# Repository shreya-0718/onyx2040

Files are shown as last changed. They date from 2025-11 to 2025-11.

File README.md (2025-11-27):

# Onyx2040
This is a devboard powered by the RP2040 chip! It features 40 pins broken out (20 per side) for easy prototyping and a plus‑sign of 5 RGB LEDs to animate whatever your heart desires.

I built this project as a way to learn full PCB design, from schematics to routing to firmware. It’s also a great way for others to prototype their own ideas, with colorful lighting built in to make experimentation more fun and expressive.

## How to Use It?
1. **Power the board** with USB-C
2. To use MicroPython, hold the button (the board will appear as a USB drive named RPI-RP2) and **flash the MicroPython UF2 firmware** with the [MicroPython RP2040 Documentation](https://www.raspberrypi.com/documentation/microcontrollers/micropython.html).
3. Once MicroPython is installed, **copy your Python files** to the board.
4. Then, **experiment!** Use the 40 broken‑out pins (GPIO, power, and ground) to connect sensors, modules, or breadboards. Check out the firmware in the /firmware folder in this repository for an example of how to control the on-board LEDs. Enjoy!

## Images
Here is the **schematic**:

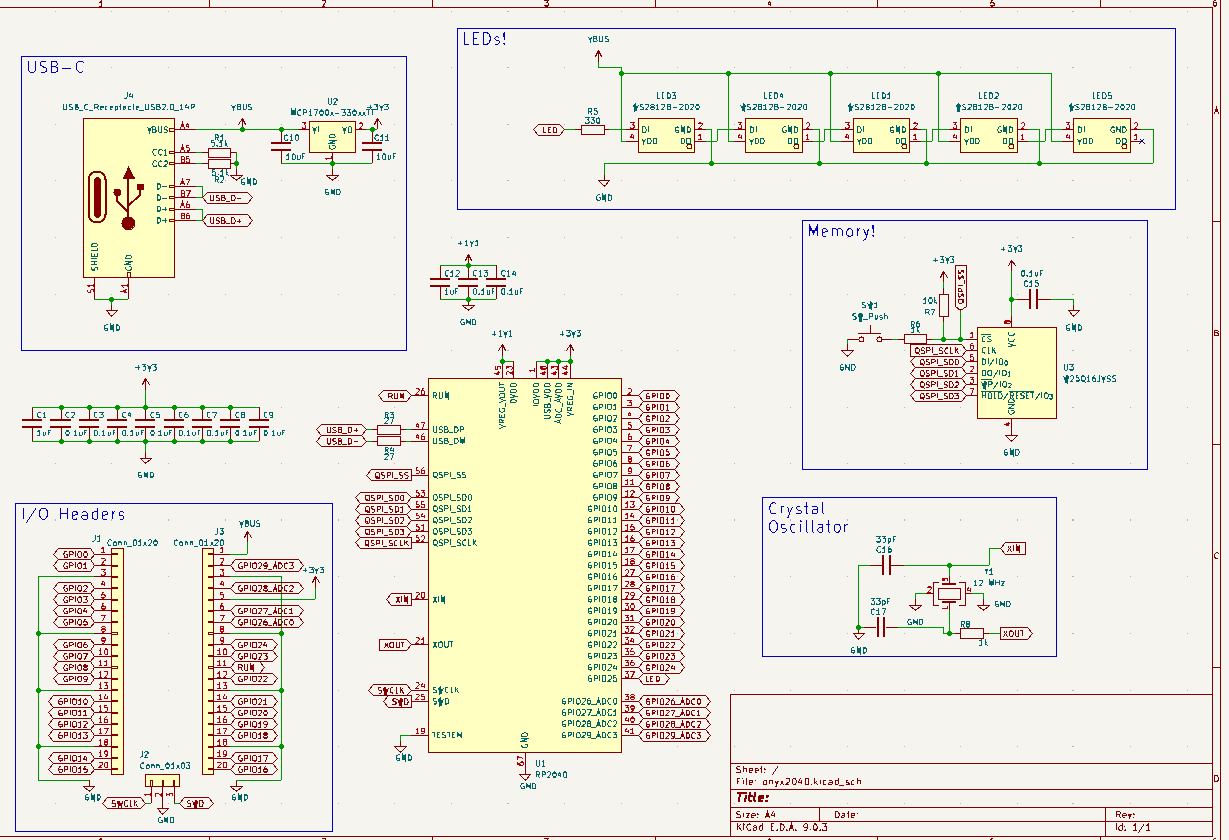
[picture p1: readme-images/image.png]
schematic


And here is the **finished PCB** in the editor:

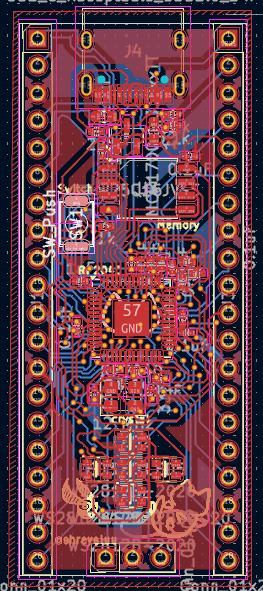
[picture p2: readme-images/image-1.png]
pcb in editor


This is what the **final devboard** will look like:

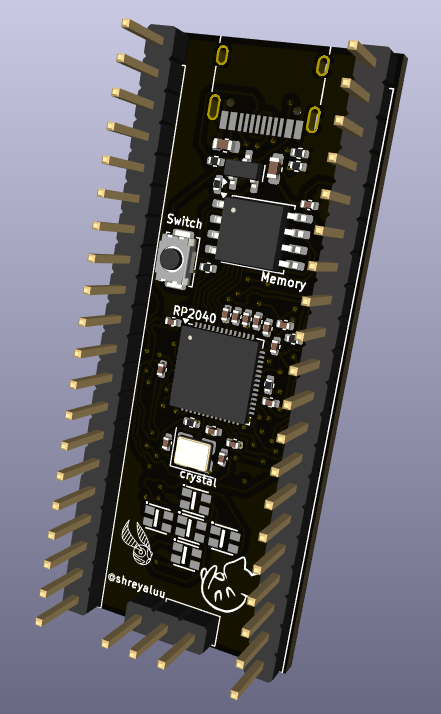
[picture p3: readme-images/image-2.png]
devboard front

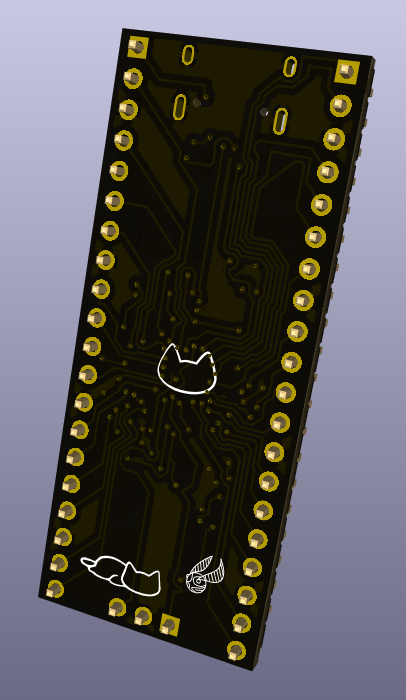
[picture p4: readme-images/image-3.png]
devboard back


## Bill of Materials (BOM)

| Item | Description | Qty | Product Link | Price w/ Tax ($) | Running Total |
|---|---|-----|---|---|---|
| Capacitor | 1µF | 2 | https://jlcpcb.com/partdetail/53938-CL05A105KA5NQNC/C52923 | $0.03 | $0.03 |
| Capacitor | 0.1µF | 11  | https://jlcpcb.com/partdetail/1877-CL05B104KO5NNNC/C1525 | $0.07 | $0.10 |
| Capacitor | 10µF | 2 | https://jlcpcb.com/partdetail/2043-CL10A106MQ8NNNC/C1691 | $0.09 | $0.19 |
| Capacitor | 33pF | 2 | https://jlcpcb.com/partdetail/1914-0402CG330J500NT/C1562 | $0.01 | $0.20 |
| Resistor | 5.1kΩ | 2 | https://jlcpcb.com/partdetail/26648-0402WGF5101TCE/C25905  | $0.01 | $1.05 |
| Resistor | 27Ω | 2 | https://jlcpcb.com/partdetail/25843-0402WGF270JTCE/C25100  | $0.01 | $1.06 |
| Resistor | 330Ω | 1 | https://jlcpcb.com/partdetail/VikingTech-ARG02FTC3300/C284512 | $0.13 | $1.19 |
| Resistor | 1kΩ | 2 | https://jlcpcb.com/partdetail/12256-0402WGF1001TCE/C11702  | $0.01 | $1.19 |
| Resistor | 10kΩ | 1 | https://jlcpcb.com/partdetail/26487-0402WGF1002TCE/C25744  | $0.00 | $1.20 |
| SW Push | Button | 1 | https://www.lcsc.com/product-detail/C720477.html | $0.42 | $11.33 |
| WS2812B-2020 | RGB SMD LEDs | 5 | https://www.lcsc.com/product-detail/C965555.html | — | $1.04 |
| RP2040 | Microcontroller | 1 | https://jlcpcb.com/partdetail/RaspberryPi-RP2040/C2040 | $4.58 | $5.78 |
| USB Receptacle  | USB-C (USB2.0, 14P) | 1 | https://jlcpcb.com/partdetail/Korean_HropartsElec-TYPE_C_31_M12/C165948 | $0.85 | $1.04 |
| MCP1700x-330xxTT| Voltage Regulator | 1 | https://jlcpcb.com/partdetail/MicrochipTech-MCP1700T_3302ETT/C39051 | $1.97 | $7.75 |
| W25Q16JVSS | Firmware storage | 1 | https://jlcpcb.com/partdetail/WinbondElec-W25Q16JVSSIQ/C82317 | $2.67 | $10.42 |
| Crystal | Quartz resonator, 12 MHz | 1 | https://jlcpcb.com/partdetail/YXC_CrystalOscillators-X322512MSB4SI/C9002 | $0.32 | $10.74 |
| Conn_01x03 | 1x03 Pin Header | 1 | https://www.lcsc.com/product-detail/C42431804.html | $0.00 | $10.74 |
| Conn_01x20 | 1x20 Pin Headers | 2 | https://www.lcsc.com/product-detail/C42431804.html | $0.17 | $10.91 |
| Onyx2040 PCBA | Board assembly | 1 | https://cart.jlcpcb.com/ | $43.94 | $54.85 |

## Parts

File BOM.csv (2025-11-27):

Item | Description | Quantity | Product link | Price w/ Tax ($) | Running Total
Capacitor | 1uF | 2 | https://jlcpcb.com/partdetail/53938-CL05A105KA5NQNC/C52923 | $0.03 | $0.03
Capacitor | 0.1uF | 11 | https://jlcpcb.com/partdetail/1877-CL05B104KO5NNNC/C1525 | $0.07 | $0.10
Capacitor | 10uF | 2 | https://jlcpcb.com/partdetail/2043-CL10A106MQ8NNNC/C1691 | $0.09 | $0.19
Capacitor | 33pF | 2 | https://jlcpcb.com/partdetail/1914-0402CG330J500NT/C1562 | $0.01 | $0.20
Resistor | 5.1k | 2 | https://jlcpcb.com/partdetail/26648-0402WGF5101TCE/C25905 | $0.01 | $1.05
Resistor | 27 | 2 | https://jlcpcb.com/partdetail/25843-0402WGF270JTCE/C25100 | $0.01 | $1.06
Resistor | 330 | 1 | https://jlcpcb.com/partdetail/VikingTech-ARG02FTC3300/C284512 | $0.13 | $1.19
Resistor | 1k | 2 | https://jlcpcb.com/partdetail/12256-0402WGF1001TCE/C11702 | $0.01 | $1.19
Resistor | 10k | 1 | https://jlcpcb.com/partdetail/26487-0402WGF1002TCE/C25744 | $0.00 | $1.20
SW_Push | Button | 1 | https://www.lcsc.com/product-detail/C720477.html | $0.42 | $11.33
WS2812B-2020 | RGB SMD LEDs | 5 | https://www.lcsc.com/product-detail/C965555.html |  | $1.04
RP2040 | Microcontroller | 1 | https://jlcpcb.com/partdetail/RaspberryPi-RP2040/C2040 | $4.58 | $5.78
USB Receptacle | USB-C (USB2.0_14P) | 1 | https://jlcpcb.com/partdetail/Korean_HropartsElec-TYPE_C_31_M12/C165948 | $0.85 | $1.04
MCP1700x-330xxTT | Voltage Regulator | 1 | https://jlcpcb.com/partdetail/MicrochipTech-MCP1700T_3302ETT/C39051 | $1.97 | $7.75
W25Q16JVSS | Firmware storage | 1 | https://jlcpcb.com/partdetail/WinbondElec-W25Q16JVSSIQ/C82317 | $2.67 | $10.42
Crystal, SMD 3225, 4-Pin | Quartz resonator, 12 MHz | 1 | https://jlcpcb.com/partdetail/YXC_CrystalOscillators-X322512MSB4SI/C9002 | $0.32 | $10.74
Conn_01x03 | 1x03 Pin Header | 1 | https://www.lcsc.com/product-detail/C42431804.html | $0.00 | $10.74
Conn_01x20 | 1x20 Pin Headers | 2 | https://www.lcsc.com/product-detail/C42431804.html | $0.17 | $10.91
Onyx2040 PCBA | PCBA board assembly | 1 | N/A (https://cart.jlcpcb.com/) | $43.94 | $54.85

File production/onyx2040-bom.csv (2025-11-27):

Id | Designator | Footprint | Quantity | Comment | Supplier and ref
1 | R1,R2 | R_0402_1005Metric | 2 | 5.1k
2 | LED1,LED5,LED4,LED2,LED3 | LED-SMD_4P-L2.0-W2.0-TL_WS2812B-2020 | 5 | WS2812B-2020
3 | R4,R3 | R_0402_1005Metric | 2 | 27
4 | C6,C7,C9,C4,C15,C5,C13,C8,C14,C2,C3 | C_0402_1005Metric | 11 | 0.1uF
5 | J3,J1 | PinHeader_1x20_P2.54mm_Vertical | 2 | Conn_01x20
6 | U3 | SOIC-8_5.3x5.3mm_P1.27mm | 1 | W25Q16JVSS
7 | R7 | R_0402_1005Metric | 1 | 10k
8 | C16,C17 | C_0402_1005Metric | 2 | 33pF
9 | C1,C12 | C_0402_1005Metric | 2 | 1uF
10 | R5 | R_0402_1005Metric | 1 | 330
11 | U1 | QFN-56-1EP_7x7mm_P0.4mm_EP3.2x3.2mm | 1 | RP2040
12 | Y1 | Crystal_SMD_3225-4Pin_3.2x2.5mm | 1 | 12 MHz
13 | R6,R8 | R_0402_1005Metric | 2 | 1k
14 | C10,C11 | C_0603_1608Metric | 2 | 10uF
15 | U2 | SOT-23 | 1 | MCP1700x-330xxTT
16 | J4 | USB_C_Receptacle_HRO_TYPE-C-31-M-12 | 1 | USB_C_Receptacle_USB2.0_14P
17 | J2 | PinHeader_1x03_P2.54mm_Vertical | 1 | Conn_01x03
18 | SW1 | SW_Push_SPST_NO_Alps_SKRK | 1 | SW_Push

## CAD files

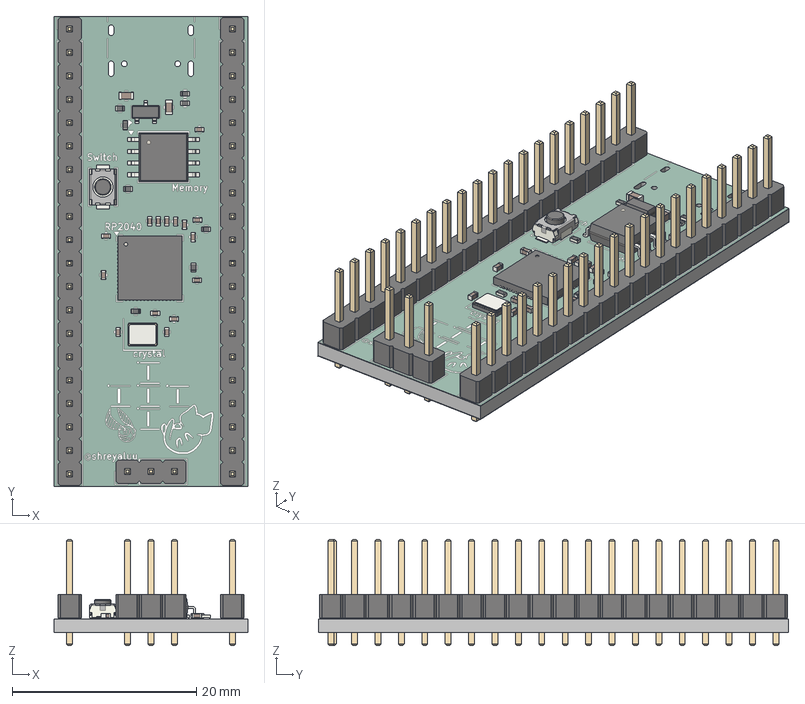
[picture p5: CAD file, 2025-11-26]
cad/onyx2040.step
21.0 x 51.0 x 11.5 mm
R_0402_1005Metric x 8
C_0402_1005Metric x 15
PinHeader_1x20_P2.54mm_Vertical x 2
SOIC-8_5.3x5.3mm_P1.27mm
QFN-56-1EP_7x7mm_P0.4mm_EP3.2x3.2mm
Crystal_SMD_3225-4Pin_3.2x2.5mm
C_0603_1608Metric x 2
SOT-23
PinHeader_1x03_P2.54mm_Vertical
SW_Push_SPST_NO_Alps_SKRK
onyx2040_silkscreen
onyx2040_soldermask
onyx2040_PCB

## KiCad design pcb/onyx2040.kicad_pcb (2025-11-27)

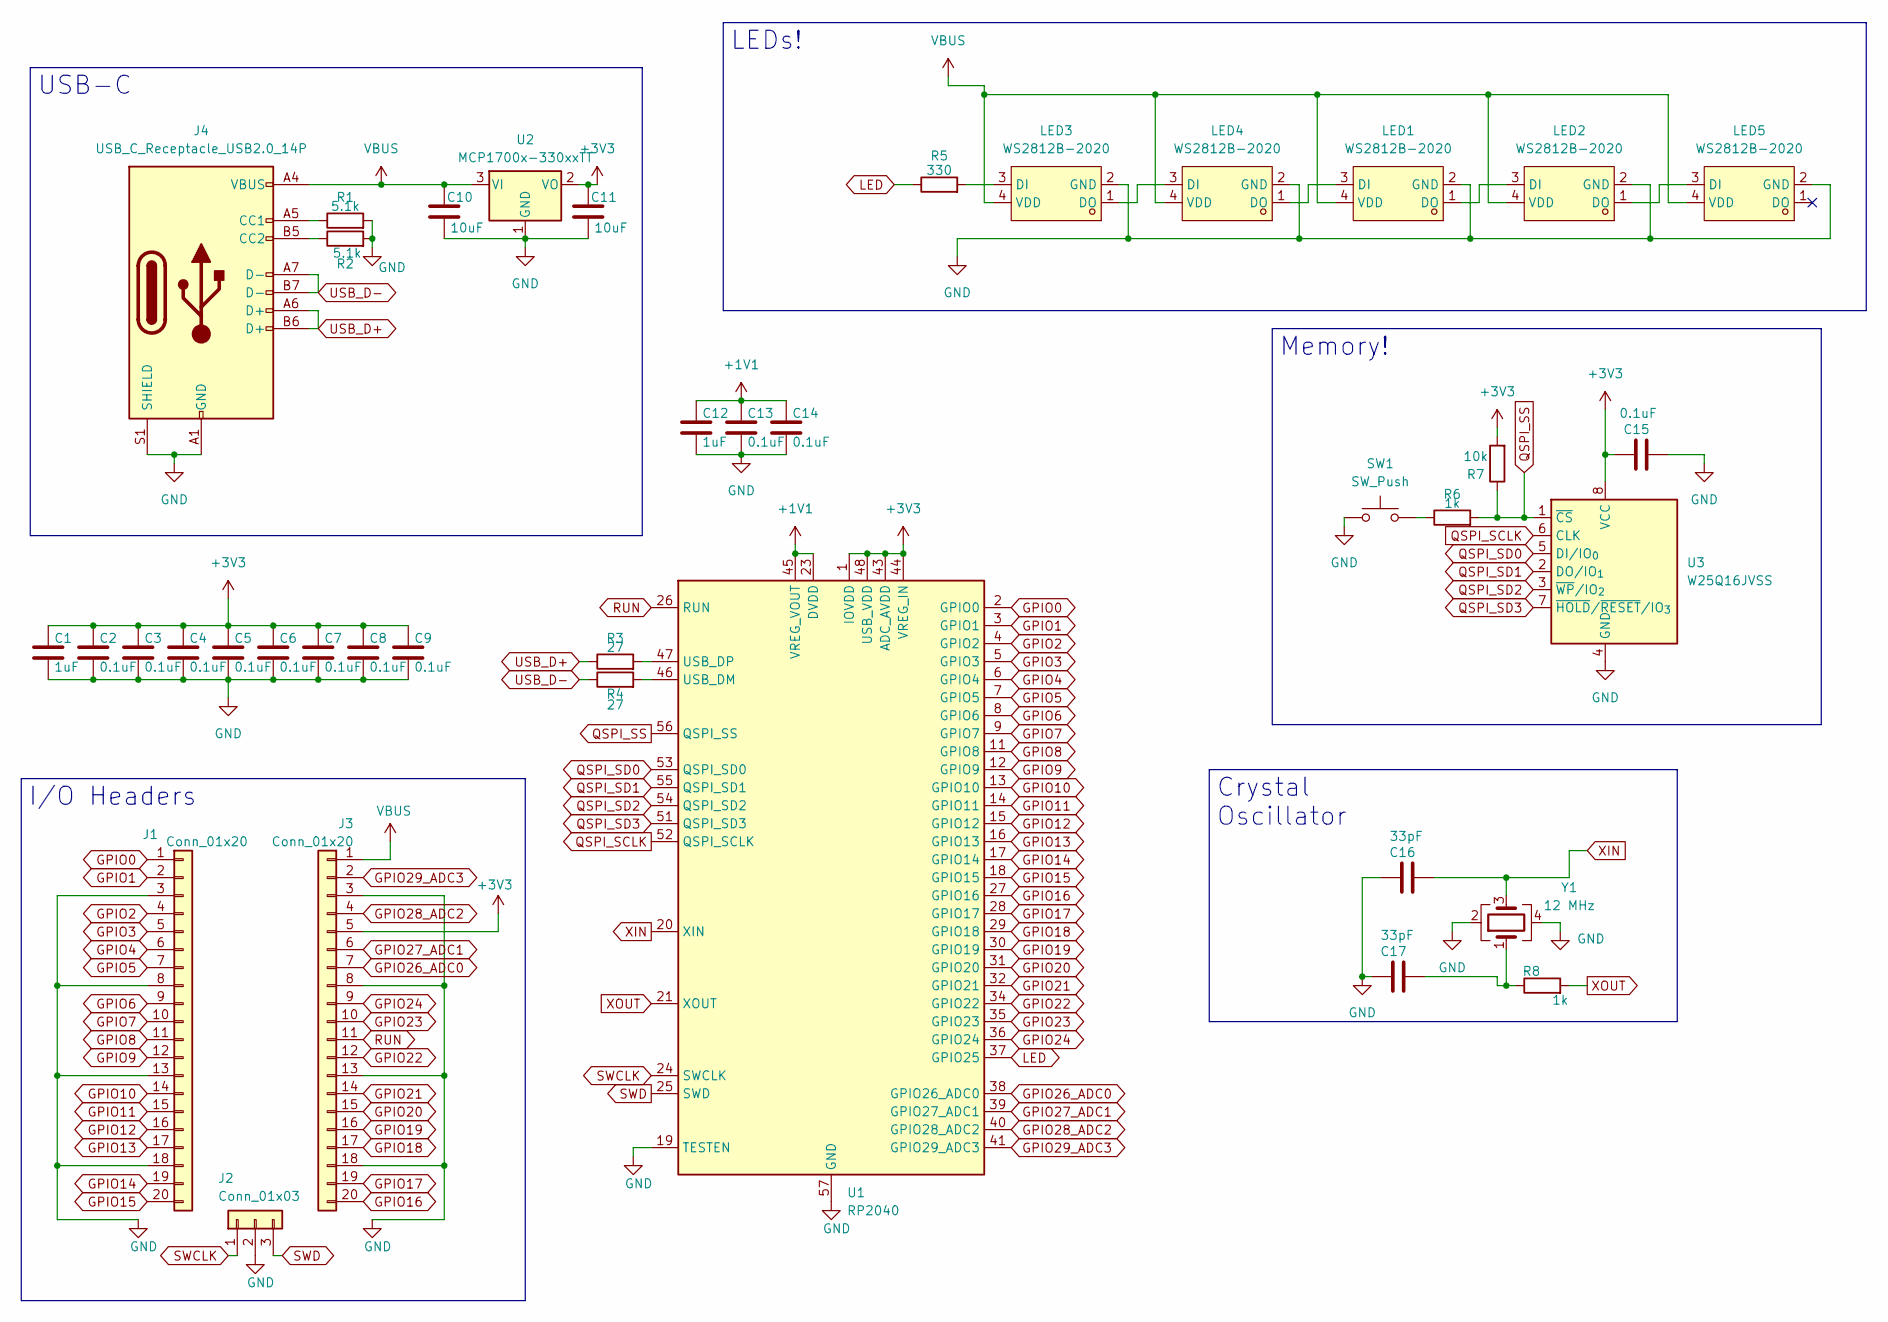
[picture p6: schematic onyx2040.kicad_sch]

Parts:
C1, C12: 1uF; C_0402_1005Metric
C2, C3, C4, C5, C6, C7, C8, C9, C13, C14, C15: 0.1uF; C_0402_1005Metric
C10, C11: 10uF; C_0603_1608Metric
C16, C17: 33pF; C_0402_1005Metric
J1, J3: Conn_01x20; PinHeader_1x20_P2.54mm_Vertical
J2: Conn_01x03; PinHeader_1x03_P2.54mm_Vertical
J4: USB_C_Receptacle_USB2.0_14P; USB_C_Receptacle_HRO_TYPE-C-31-M-12
LED1, LED2, LED3, LED4, LED5: WS2812B-2020; LED-SMD_4P-L2.0-W2.0-TL_WS2812B-2020; LCSC Part C965555
R1, R2: 5.1k; R_0402_1005Metric
R3, R4: 27; R_0402_1005Metric
R5: 330; R_0402_1005Metric
R6, R8: 1k; R_0402_1005Metric
R7: 10k; R_0402_1005Metric
SW1: SW_Push; SW_Push_SPST_NO_Alps_SKRK
U1: RP2040; QFN-56-1EP_7x7mm_P0.4mm_EP3.2x3.2mm
U2: MCP1700x-330xxTT; SOT-23
U3: W25Q16JVSS; SOIC-8_5.3x5.3mm_P1.27mm
Y1: 12 MHz; Crystal_SMD_3225-4Pin_3.2x2.5mm

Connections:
+1V1: C12.1, C13.1, C14.1, U1.23 (DVDD), U1.45 (VREG_VOUT), U1.50 (DVDD)
+3V3: C1.1, C2.1, C3.1, C4.1, C5.1, C6.1, C7.1, C8.1, C9.1, C11.1, C15.1, J3.5, R7.2, U1.1 (IOVDD), U1.10 (IOVDD), U1.22 (IOVDD), U1.33 (IOVDD), U1.42 (IOVDD), U1.43 (ADC_AVDD), U1.44 (VREG_IN), U1.48 (USB_VDD), U1.49 (IOVDD), U2.2 (VO), U3.8 (VCC)
GND: C1.2, C2.2, C3.2, C4.2, C5.2, C6.2, C7.2, C8.2, C9.2, C10.2, C11.2, C12.2, C13.2, C14.2, C15.2, C16.1, C17.1, J1.3, J1.8, J1.13, J1.18, J2.2, J3.3, J3.8, J3.13, J3.18, J4.A1 (GND), J4.A12 (GND), J4.B1 (GND), J4.B12 (GND), J4.S1 (SHIELD), LED1.2 (GND), LED2.2 (GND), LED3.2 (GND), LED4.2 (GND), LED5.2 (GND), R1.2, R2.2, SW1.1, U1.19 (TESTEN), U1.57 (GND), U2.1 (GND), U3.4 (GND), Y1.2, Y1.4
GPIO0: J1.1, U1.2 (GPIO0)
GPIO1: J1.2, U1.3 (GPIO1)
GPIO2: J1.4, U1.4 (GPIO2)
GPIO3: J1.5, U1.5 (GPIO3)
GPIO4: J1.6, U1.6 (GPIO4)
GPIO5: J1.7, U1.7 (GPIO5)
GPIO6: J1.9, U1.8 (GPIO6)
GPIO7: J1.10, U1.9 (GPIO7)
GPIO8: J1.11, U1.11 (GPIO8)
GPIO9: J1.12, U1.12 (GPIO9)
GPIO10: J1.14, U1.13 (GPIO10)
GPIO11: J1.15, U1.14 (GPIO11)
GPIO12: J1.16, U1.15 (GPIO12)
GPIO13: J1.17, U1.16 (GPIO13)
GPIO14: J1.19, U1.17 (GPIO14)
GPIO15: J1.20, U1.18 (GPIO15)
GPIO16: J3.20, U1.27 (GPIO16)
GPIO17: J3.19, U1.28 (GPIO17)
GPIO18: J3.17, U1.29 (GPIO18)
GPIO19: J3.16, U1.30 (GPIO19)
GPIO20: J3.15, U1.31 (GPIO20)
GPIO21: J3.14, U1.32 (GPIO21)
GPIO22: J3.12, U1.34 (GPIO22)
GPIO23: J3.10, U1.35 (GPIO23)
GPIO24: J3.9, U1.36 (GPIO24)
GPIO26_ADC0: J3.7, U1.38 (GPIO26_ADC0)
GPIO27_ADC1: J3.6, U1.39 (GPIO27_ADC1)
GPIO28_ADC2: J3.4, U1.40 (GPIO28_ADC2)
GPIO29_ADC3: J3.2, U1.41 (GPIO29_ADC3)
LED: R5.1, U1.37 (GPIO25)
unnamed: C17.2, R8.1, Y1.1
unnamed: J4.A5 (CC1), R1.1
unnamed: J4.B5 (CC2), R2.1
unnamed: LED1.3 (DI), LED4.1 (DO)
unnamed: LED1.1 (DO), LED2.3 (DI)
unnamed: LED2.1 (DO), LED5.3 (DI)
unnamed: LED3.3 (DI), R5.2
unnamed: LED3.1 (DO), LED4.3 (DI)
unnamed: R6.1, SW1.2
unnamed: R4.2, U1.46 (USB_DM)
unnamed: R3.2, U1.47 (USB_DP)
QSPI_SCLK: U1.52 (QSPI_SCLK), U3.6 (CLK)
QSPI_SD0: U1.53 (QSPI_SD0), U3.5 (DI/IO_{0})
QSPI_SD1: U1.55 (QSPI_SD1), U3.2 (DO/IO_{1})
QSPI_SD2: U1.54 (QSPI_SD2), U3.3 (~WP/IO_{2})
QSPI_SD3: U1.51 (QSPI_SD3), U3.7 (~HOLD/~RESET/IO_{3})
QSPI_SS: R6.2, R7.1, U1.56 (QSPI_SS), U3.1 (~CS)
RUN: J3.11, U1.26 (RUN)
SWCLK: J2.1, U1.24 (SWCLK)
SWD: J2.3, U1.25 (SWD)
USB_D+: J4.A6 (D+), J4.B6 (D+), R3.1
USB_D-: J4.A7 (D-), J4.B7 (D-), R4.1
VBUS: C10.1, J3.1, J4.A4 (VBUS), J4.A9 (VBUS), J4.B4 (VBUS), J4.B9 (VBUS), LED1.4 (VDD), LED2.4 (VDD), LED3.4 (VDD), LED4.4 (VDD), LED5.4 (VDD), U2.3 (VI)
XIN: C16.2, U1.20 (XIN), Y1.3
XOUT: R8.2, U1.21 (XOUT)

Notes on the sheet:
Memory!
I/O Headers
Crystal Oscillator
LEDs!
USB-C

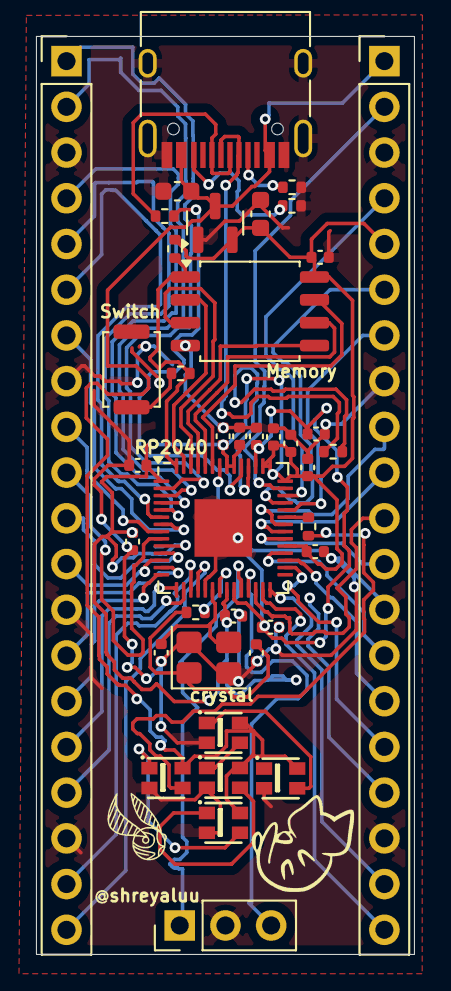
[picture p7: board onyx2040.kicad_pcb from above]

Board: 2 copper layers, 21.0 x 51.0 mm, 39 parts (0 on the bottom side), 58 nets.

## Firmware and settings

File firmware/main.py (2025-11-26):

# https://datasheets.raspberrypi.com/pico/raspberry-pi-pico-python-sdk.pdf
#  3.9.2. WS2812 LED (NeoPixel)

import array, time
from machine import Pin
import rp2

NUM_LEDS = 5

# assembly code for the PIO from micropy docs
@rp2.asm_pio(sideset_init=rp2.PIO.OUT_LOW,
             out_shiftdir=rp2.PIO.SHIFT_LEFT,
             autopull=True, pull_thresh=24)
def ws2812():
    T1 = 2
    T2 = 5
    T3 = 3
    wrap_target()
    label("bitloop")
    out(x, 1)               .side(0)    [T3 - 1]
    jmp(not_x, "do_zero")   .side(1)    [T1 - 1]
    jmp("bitloop")          .side(1)    [T2 - 1]
    label("do_zero")
    nop()                   .side(0)    [T2 - 1]
    wrap()

def pack_color(r, g, b):
    # (RED << 16) | (GREEN << 8) | BLUE
    return (r << 16) | (g << 8) | b

# StateMachine on GPIO25
sm = rp2.StateMachine(0, ws2812, freq=8_000_000, sideset_base=Pin(25))
sm.active(1)

ar = array.array("I", [0 for _ in range(NUM_LEDS)])
CENTER, TOP, RIGHT, BOTTOM, LEFT = 0, 1, 2, 3, 4

for i in range(10):
    for led in [TOP, RIGHT, BOTTOM, LEFT]:
        for j in range(NUM_LEDS):
            ar[j] = 0
        
        ar[CENTER] = pack_color(8,8,8)

        ar[led] = pack_color(128,0,0)

        # sends data to LEDs
        for val in ar:
            sm.put(val)
        # sm.put(ar, 8)

        time.sleep_ms(200)

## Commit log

2025-11-26 publish to main
    [nimbus2040.kicad_pcb, nimbus2040.kicad_sch]
2025-11-26 added cad file
    [onyx2040.kicad_pcb, onyx2040.kicad_sch, onyx2040.step]
2025-11-26 added firmware code
    [onyx2040.kicad_pcb]
2025-11-27 made BOM! and production files!
    [onyx2040-B_Cu.gbr, onyx2040-B_Mask.gbr, onyx2040-B_Paste.gbr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]
2025-11-27 cleaned up pcb files
    [onyx2040-B_Cu.gbr, onyx2040-B_Mask.gbr, onyx2040-B_Paste.gbr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]
2025-11-27 removed bom from gitignore
    [BOM.csv, onyx2040-bom.csv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]
2025-11-27 update BOM
2025-11-28 changed color of pcb
